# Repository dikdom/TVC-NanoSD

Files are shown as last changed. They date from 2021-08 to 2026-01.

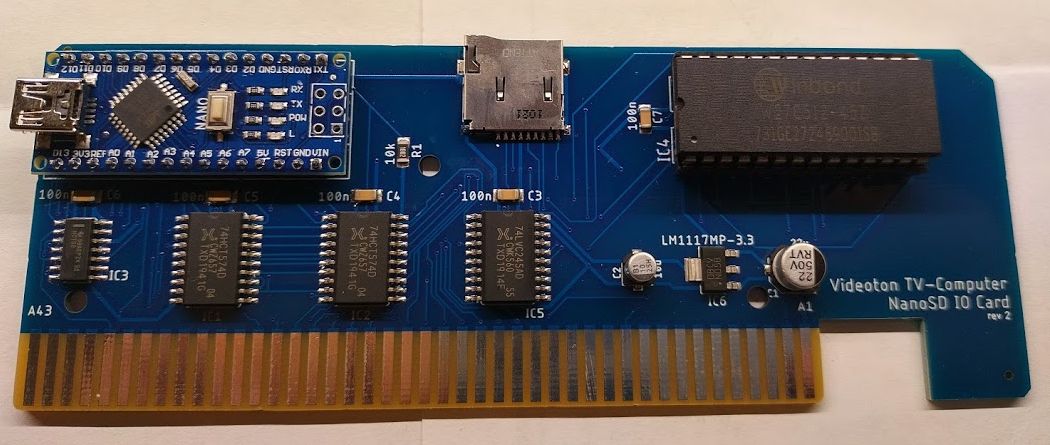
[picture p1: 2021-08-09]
doc/TVC-NanoSD-IO-r2.jpg

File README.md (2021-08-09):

# TVC-NanoSD
A microSD card handler IO card for the Videoton TV Computer.
Egy microSD kártya kezelő IO kártya a Videoton TV Computer számára.

## License
BSD 3-Clause License

## Description
This is a simple and cheap microSD handler card for the Hunarian 8 bit TVC computer. It emulates the cassette interface so it can load
and save .CAS files, it can read and write data files.

## Leírás
Ez egy egyszerű és viszonylag olcsón összerakható microSD kártya kezelő IO modul a magyar 8bites TVC számítógép felső bővítőjébe. A magnó 
interface-t emulálja, így .CAS file-okat olvas és ír (LOAD és SAVE parancs működik) illetve sima adat file-okat is létre lehet hozni vele
az SD kártyán.

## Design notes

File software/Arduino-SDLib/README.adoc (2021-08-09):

:repository-owner: arduino-libraries
:repository-name: SD

= {repository-name} Library for Arduino =





The SD library allows for reading from and writing to SD cards.

For more information about this library please visit us at
http://www.arduino.cc/en/Reference/{repository-name}

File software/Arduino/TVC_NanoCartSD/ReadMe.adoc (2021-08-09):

:Author: sanyi
:Email: {AuthorEmail}
:Date: 19/01/2021
:Revision: version#
:License: Public Domain

= Project: {Project}

Describe your project

== Step 1: Installation
Please describe the steps to install this project.

For example:

1. Open this file
2. Edit as you like
3. Release to the World!

== Step 2: Assemble the circuit

Assemble the circuit following the diagram layout.png attached to the sketch

== Step 3: Load the code

Upload the code contained in this sketch on to your board

=== Folder structure

....
 sketch123                => Arduino sketch folder
  ├── sketch123.ino       => main Arduino file
  ├── schematics.png      => (optional) an image of the required schematics
  ├── layout.png          => (optional) an image of the layout
  └── ReadMe.adoc         => this file
....

=== License
This project is released under a {License} License.

=== Contributing
To contribute to this project please contact sanyi https://id.arduino.cc/sanyi

=== BOM
Add the bill of the materials you need for this project.

|===
| ID | Part name      | Part number | Quantity
| R1 | 10k Resistor   | 1234-abcd   | 10
| L1 | Red LED        | 2345-asdf   | 5
| A1 | Arduino Zero   | ABX00066    | 1
|===

=== Help
This document is written in the _AsciiDoc_ format, a markup language to describe documents.
If you need help you can search the http://www.methods.co.nz/asciidoc[AsciiDoc homepage]
or consult the http://powerman.name/doc/asciidoc[AsciiDoc cheatsheet]

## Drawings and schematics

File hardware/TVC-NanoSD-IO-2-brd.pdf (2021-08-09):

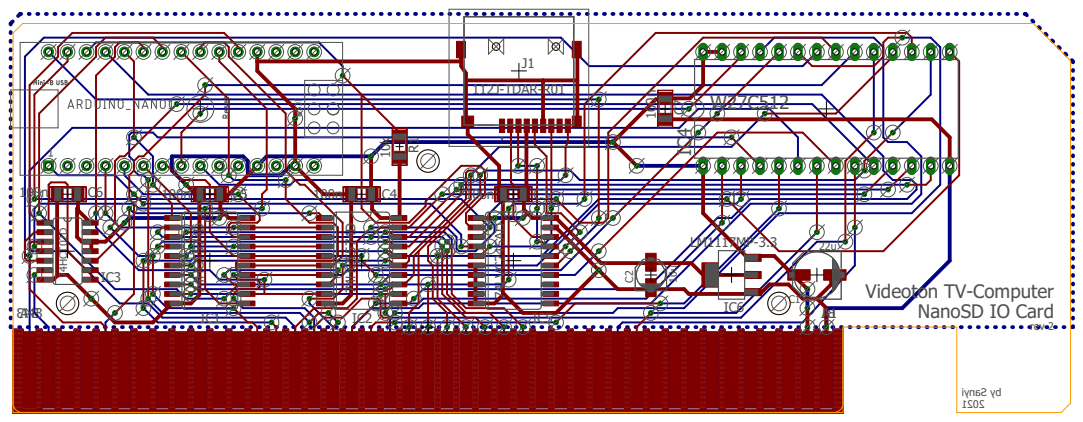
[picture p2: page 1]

i ynaS yb 1202 34B 1B Videoton TV-Computer NanoSD IO Card rev 2 A43 A1 IC1 IC2 IC3 IC4 IC5 C6 C5 C4 C3 J1 R1 IC6 C2 C1 C7 74HCT574D 74HCT574D 74HCT02D W27C512 74LVC245AD 100n 100n 100n 100n 112J-TDAR-R01 10k LM1117MP-3.3 10u 22u 100n

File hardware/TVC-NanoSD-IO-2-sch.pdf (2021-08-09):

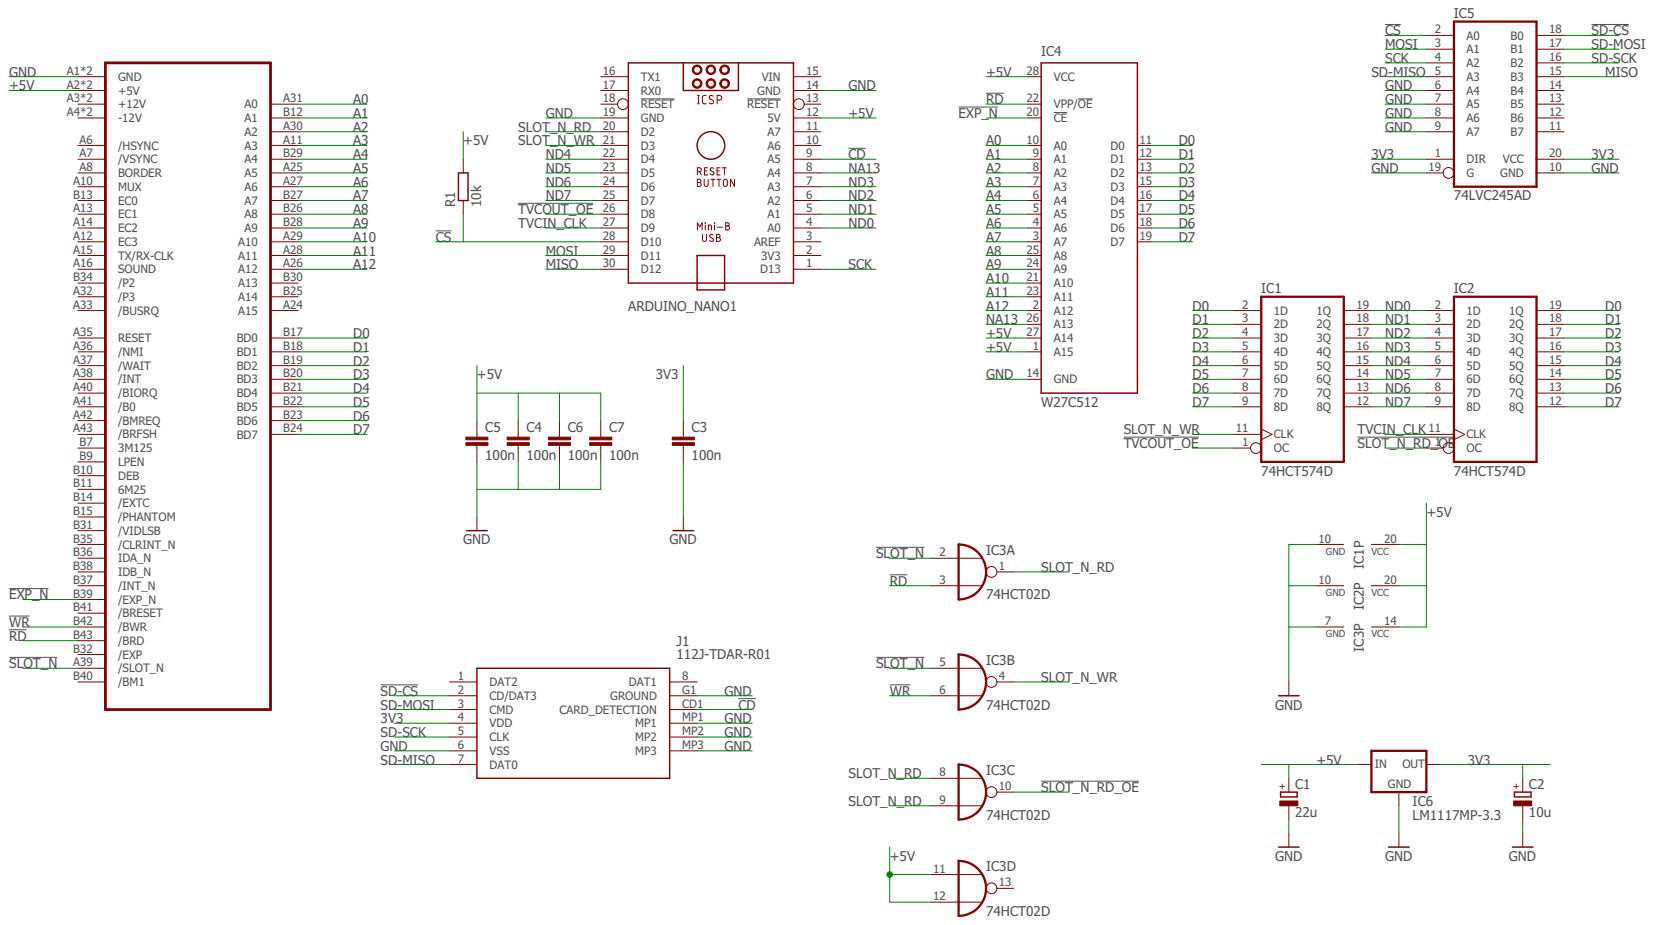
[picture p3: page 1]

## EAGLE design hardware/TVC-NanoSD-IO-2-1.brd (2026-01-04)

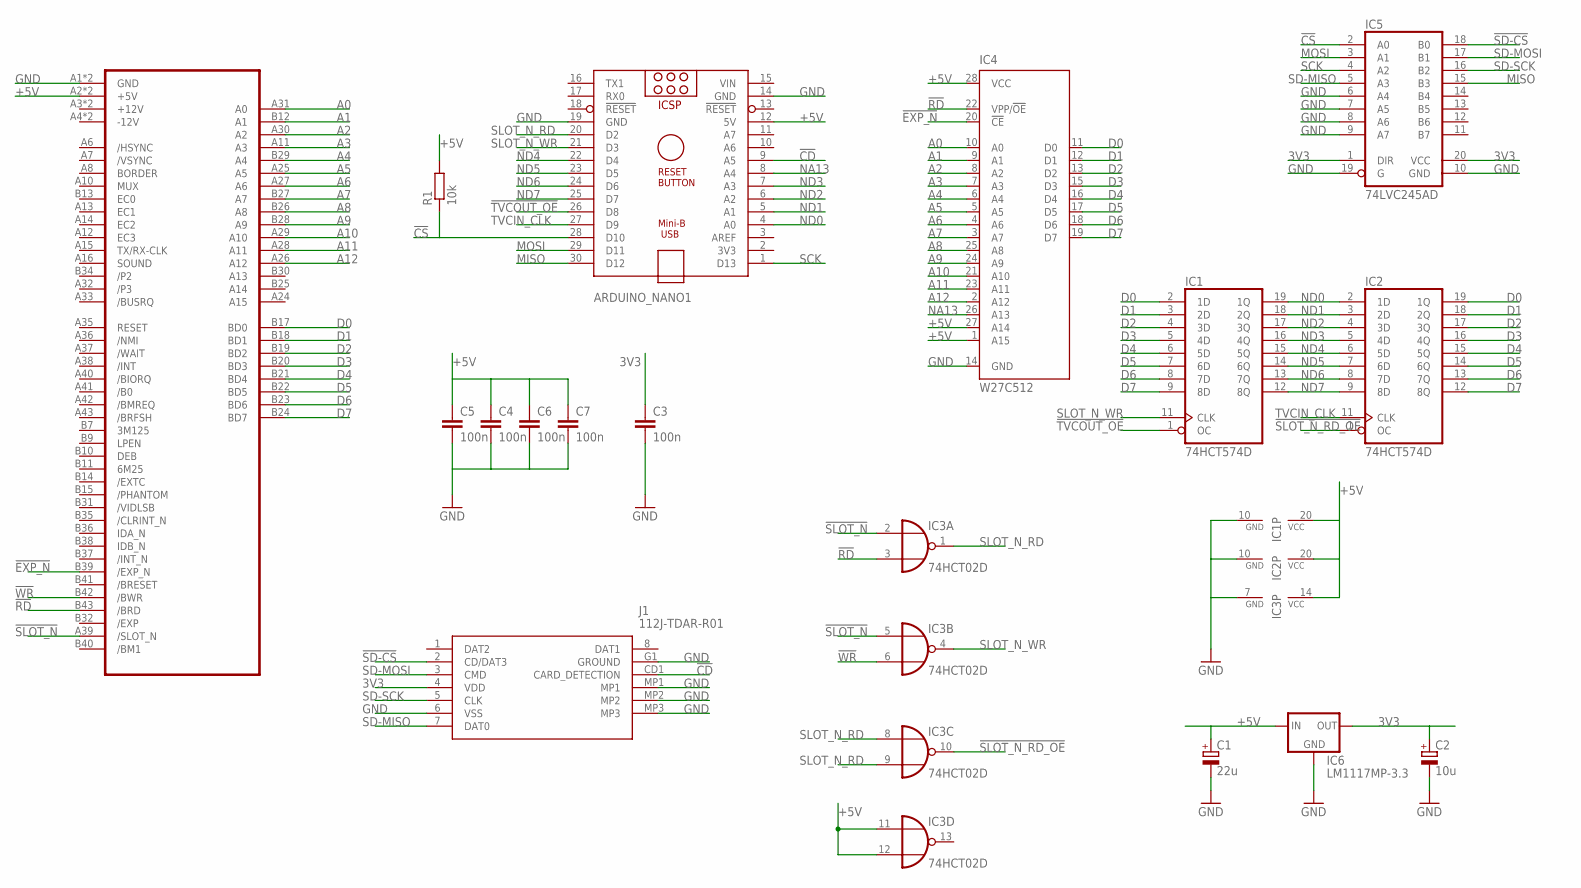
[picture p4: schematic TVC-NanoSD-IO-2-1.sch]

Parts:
ARDUINO_NANO1: ARDUINO_NANO
C1: 22u; PANASONIC_D
C2: 10u; PANASONIC_B
C3, C4, C5, C6, C7: 100n; C1206
CON1: TVC-EXP-HBA-COMMON; TVC-EXP-EDGE
IC1, IC2: 74HCT574D; SO20W
IC3: 74HCT02D; SO14
IC4: W27C512; DIL28-6
IC5: 74LVC245AD; SO20W
IC6: LM1117MP-3.3; SOT223
J1: 112J-TDAR-R01; 112JTDARR01
R1: 10k; R1206

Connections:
3V3: C2.+, C3.1, IC5.1 (DIR), IC5.20 (VCC), IC6.2 (OUT), IC6.4 (OUT), J1.4 (VDD)
!CD: ARDUINO_NANO1.9 (A5), J1.CD1 (CARD_DETECTION)
!CS: ARDUINO_NANO1.28 (D10), IC5.2 (A0), R1.1
!EXP_N: CON1.B39 (/EXP_N), IC4.20 (!CE)
!RD: CON1.B43 (/BRD), IC3.3 (I1), IC4.22 (VPP/!OE)
!SD-CS: IC5.18 (B0), J1.2 (CD/DAT3)
!SLOT_N: CON1.A39 (/SLOT_N), IC3.2 (I0), IC3.5 (I0)
!SLOT_N_RD_OE: IC2.1 (OC), IC3.10 (O)
!TVCOUT_OE: ARDUINO_NANO1.26 (D8), IC1.1 (OC)
!WR: CON1.B42 (/BWR), IC3.6 (I1)
+5V: ARDUINO_NANO1.12 (5V), C1.+, C4.1, C5.1, C6.1, C7.1, CON1.A2 (+5V), CON1.B2 (+5V), IC1.20 (VCC), IC2.20 (VCC), IC3.11 (I0), IC3.12 (I1), IC3.14 (VCC), IC4.1 (A15), IC4.27 (A14), IC4.28 (VCC), IC6.3 (IN), R1.2
A0: CON1.A31 (A0), IC4.10 (A0)
A1: CON1.B12 (A1), IC4.9 (A1)
A2: CON1.A30 (A2), IC4.8 (A2)
A3: CON1.A11 (A3), IC4.7 (A3)
A4: CON1.B29 (A4), IC4.6 (A4)
A5: CON1.A25 (A5), IC4.5 (A5)
A6: CON1.A27 (A6), IC4.4 (A6)
A7: CON1.B27 (A7), IC4.3 (A7)
A8: CON1.B26 (A8), IC4.25 (A8)
A9: CON1.B28 (A9), IC4.24 (A9)
A10: CON1.A29 (A10), IC4.21 (A10)
A11: CON1.A28 (A11), IC4.23 (A11)
A12: CON1.A26 (A12), IC4.2 (A12)
D0: CON1.B17 (BD0), IC1.2 (1D), IC2.19 (1Q), IC4.11 (D0)
D1: CON1.B18 (BD1), IC1.3 (2D), IC2.18 (2Q), IC4.12 (D1)
D2: CON1.B19 (BD2), IC1.4 (3D), IC2.17 (3Q), IC4.13 (D2)
D3: CON1.B20 (BD3), IC1.5 (4D), IC2.16 (4Q), IC4.15 (D3)
D4: CON1.B21 (BD4), IC1.6 (5D), IC2.15 (5Q), IC4.16 (D4)
D5: CON1.B22 (BD5), IC1.7 (6D), IC2.14 (6Q), IC4.17 (D5)
D6: CON1.B23 (BD6), IC1.8 (7D), IC2.13 (7Q), IC4.18 (D6)
D7: CON1.B24 (BD7), IC1.9 (8D), IC2.12 (8Q), IC4.19 (D7)
GND: ARDUINO_NANO1.14 (GND), ARDUINO_NANO1.19 (GND), C1.-, C2.-, C3.2, C4.2, C5.2, C6.2, C7.2, CON1.A1 (GND), CON1.B1 (GND), IC1.10 (GND), IC2.10 (GND), IC3.7 (GND), IC4.14 (GND), IC5.6 (A4), IC5.7 (A5), IC5.8 (A6), IC5.9 (A7), IC5.10 (GND), IC5.19 (G), IC6.1 (GND), J1.6 (VSS), J1.G1 (GROUND), J1.MP1, J1.MP2, J1.MP3
MISO: ARDUINO_NANO1.30 (D12), IC5.15 (B3)
MOSI: ARDUINO_NANO1.29 (D11), IC5.3 (A1)
NA13: ARDUINO_NANO1.8 (A4), IC4.26 (A13)
ND0: ARDUINO_NANO1.4 (A0), IC1.19 (1Q), IC2.2 (1D)
ND1: ARDUINO_NANO1.5 (A1), IC1.18 (2Q), IC2.3 (2D)
ND2: ARDUINO_NANO1.6 (A2), IC1.17 (3Q), IC2.4 (3D)
ND3: ARDUINO_NANO1.7 (A3), IC1.16 (4Q), IC2.5 (4D)
ND4: ARDUINO_NANO1.22 (D4), IC1.15 (5Q), IC2.6 (5D)
ND5: ARDUINO_NANO1.23 (D5), IC1.14 (6Q), IC2.7 (6D)
ND6: ARDUINO_NANO1.24 (D6), IC1.13 (7Q), IC2.8 (7D)
ND7: ARDUINO_NANO1.25 (D7), IC1.12 (8Q), IC2.9 (8D)
SCK: ARDUINO_NANO1.1 (D13), IC5.4 (A2)
SD-MISO: IC5.5 (A3), J1.7 (DAT0)
SD-MOSI: IC5.17 (B1), J1.3 (CMD)
SD-SCK: IC5.16 (B2), J1.5 (CLK)
SLOT_N_RD: ARDUINO_NANO1.20 (D2), IC3.1 (O), IC3.8 (I0), IC3.9 (I1)
SLOT_N_WR: ARDUINO_NANO1.21 (D3), IC1.11 (CLK), IC3.4 (O)
TVCIN_CLK: ARDUINO_NANO1.27 (D9), IC2.11 (CLK)
VIN: ARDUINO_NANO1.15 (VIN)

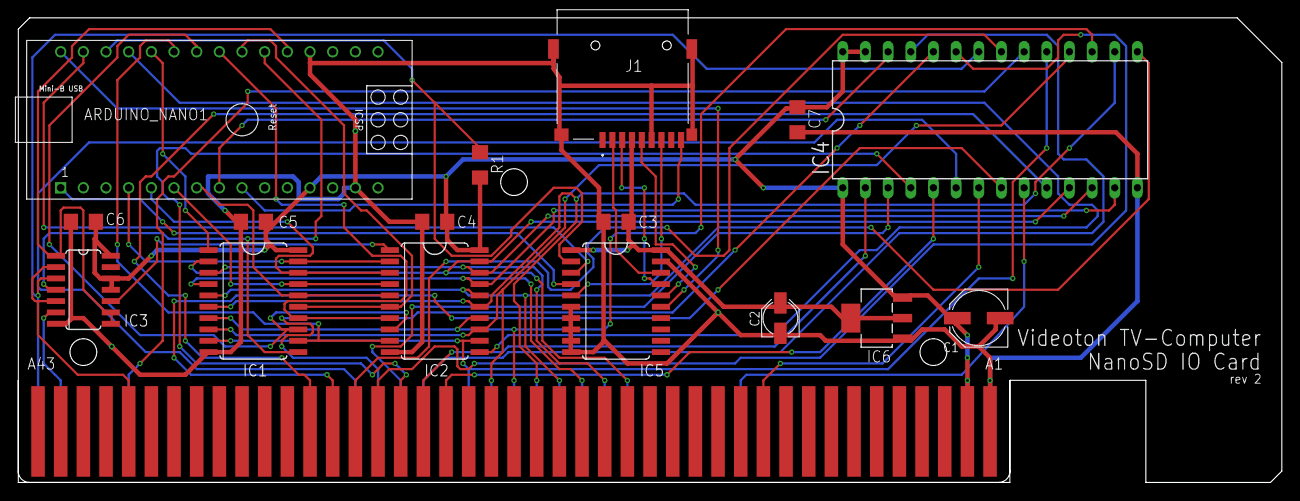
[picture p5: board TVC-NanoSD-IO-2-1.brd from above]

Board: 2 copper layers, 141.6 x 52.1 mm, 17 parts (0 on the bottom side), 51 nets.

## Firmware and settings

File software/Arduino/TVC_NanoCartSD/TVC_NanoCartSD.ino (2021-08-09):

/*
  This is the NanoSD IO Card's Arduino Nano firmware code. This is the code that communicates with TVC
  and reads/writes the SD card.

  Pins to avoid: D0, D1 (RX/TX)
  The Nano board has to have
  - 8 lines to the data bus of TVC -  PORTC0-3: BD0-BD3 (A0-A3)
                                      PORTD4-7: BD4-BD7 (pin 4-pin 7)
  - 6 lines to the control
    - /SLOTn + /RD PD2 (pin 2)  Always IN, INT0, TVC port in
    - /SLOTn + /WR PD3 (pin 3)  Always IN, INT1, TVC port out
    - /LE on TVC-IN register  PB0 (pin 8)    Always OUT
    - /OE on TVC-OUT register PB1 (pin 9)    Always OUT
    - BANK-Sel (pin A4)   Always OUT   - as of now, NanoSD EEPROM code fits in one bank, this feature is not in use
    - Card Detect PC5 (pin A5) Always IN, shall be pulled UP internally
  - 4 lines to SD card (SPI):
    - PB3, PB4, PB5 (MOSI, MISO, CLK; pin 11, 12, 13)
    - PB2 (CS; pin 10)                - Always OUTPUT

  Always TVC initiates a command
  OPEN: opens a file for reading
    TVC OUTs to address 00 an OPEN command
    then OUTs a fileName with 0 delimiter. The fileName is max 64 chars long
    TVC INs and waits for OPEN_OK or FILE_NOT_FOUND.
    WAITING_FOR_INPUT (string was not terminated properly) and DATA_NOT_READY_YET are normal, intermediate responses.
    In case of FILE_NOT_FOUND the file cannot be opened. In case of OPEN_OK then the file size can be read from stream
    (low/high byte)
  CLOSE: close a previously opened file
    TVC OUTs to address 00 a CLOSE command
    TVC INs and waits for CLOSE_OK or CLOSE_FAILED.
  GETDATA: get data content from an open file
    TVC OUTs to 00 a GETDATA command
    -- repeat from here
    TVC INs until OK, END_OF_FILE or FILE_NOT_OPEN. DATA_NOT_READY_YET is normal, intermediate response.
    END_OF_FILE means TVC read all the bytes, operation shall finish here.
    After OK, TVC continues reading and the card returns a number, how many bytes (n) are available in its
    buffer, then the data. After that TVC reads (IN from address 00) n bytes.
    After n bytes read TVC must ack the read by OUTing ACK_GETDATA and repeat the read procedure. Anything else
    than ACK_GETDATA will cancel the getData stream, empties the buffer of the card.
  LIST: list the directory of the current dir
    TVC OUTs to 00 a LIST command
    -- repeat from here
    TVC INs until OK, END_OF_LIST, CARD_NOT_READY, DATA_NOT_READY_YET. DATA_NOT_READY_YET is a normal, intermediate response.
    END_OF_LIST means there is no more files in the list and the operation shall finish here.
    After OK, the card returns null terminated string, then a type, then a size (0 in case of directory).
    After all bytes received, TVC must ACK_LIST file record and repeat the procedure.
  CHDIR: changes directory
    TVC OUTs to 00 a CHDIR command
    TVC OUTs a path as a null terminated string. Max length is 64 chars. Can be absolute or relative path. Nano code stores the working path
    as the SD library doesn't support that.
    "/" is the root directory.
    If a path starts with "/" it is handled as absolute path and that will be working directory (if it exists).
    Otherwise it is added to the stored working directory and that will be used for the subsequent CHDIR, LIST and OPEN commands
    The path may or may not ends with "/"
    TVC can receive CHDIR_OK or CHDIR_FAILED and and intermediate DATA_NOT_READY_YET or WAITING_FOR_INPUT (if path is not terminated yet).
*/

#include <SPI.h>
#include <SD.h>
#include <wiring_private.h>
#include "CircularQueue.h"
#include "PathStack.h"
#include <string.h>
#include <EEPROM.h>

#define INPUTDATABUFFER_SIZE 64+16
#define OUTPUTDATABUFFER_SIZE 64+16
#define GETDATA_SIZE 64

#define LINE_TVCOUT_OE  PB0
#define LINE_TVCIN_CLK  PB1
#define LINE_SLOTN_RD   PD2
#define LINE_SLOTN_WR   PD3
#define LINE_BANK       PC4
#define LINE_CD         PC5

#define LINE_DATA0      PC0
#define LINE_DATA1      PC1
#define LINE_DATA2      PC2
#define LINE_DATA3      PC3
#define LINE_DATA4      PD4
#define LINE_DATA5      PD5
#define LINE_DATA6      PD6
#define LINE_DATA7      PD7

#define LINE_SS         PB2
#define LINE_MISO       PB3
#define LINE_MOSI       PB4
#define LINE_CLK        PB5
#define LINE_CS         PB2  // SS is not used in Master SPI mode

#define DEBUG

enum COMMANDS { OPEN = 0, // Open a file. Parameter is a null terminated string. Returns 0: ok
                CLOSE,   // Closes the lastopen file. Returns OK
                CHDIR,   // Change dir. Parameter is a null terminated string. Returns 0:ok, 1:FILE_NOT_FOUND
                LIST,    // Gets the list of files in the current directory (fName, type, size)
                ACK_LIST, //
                GETDATA,   // Returns OK, then [num of bytes to return (GETDATA_SIZE)]. After num of bytes read TVC must send ACK_GETDATA;
                FINFO,   // Returns the file info. Param: null terminated file name.
                GETCDIR,  // Returns the current path: length of string + string
                BANKTO0,  // NOTIMPLEMENTED YET!
                BANKTO1,
                CREATE, // 0x0a gets a fileName (length + chars), fileType (0x01 or 0x11), return CREATE_OK of CREATE_FAILED
                PUTDATA,
                CLOSEWRITE,
                GETPARAMETER, // 0x0D gets a parameter from Nano
                SETPARAMETER, // 0x0E sets a parameter to Nano
                MKDIR,
                RMDIR,  // 0x10 - removes an empty directory from SDs
                DELETE,
                CDPINCHANGE_DETECTED,
                NONE = 255
              };
enum STATUS  {OK = 0,
              OPEN_OK,
              DATA_NOT_READY_YET = 0x80,  // not sent from outputQueue
              WAITING_FOR_INPUT,
              FILE_NOT_FOUND,
              END_OF_FILE,
              END_OF_LIST,
              FILE_NOT_OPEN,              // 0x85
              CARD_NOT_READY,
              READ_OUT_OF_SYNC,
              BUFFER_OVERRUN,
              BUFFER_UNDERRUN,
              CLOSE_OK,                     // 0x8a
              CLOSE_FAILED,
              CHDIR_OK,
              CHDIR_FAILED,                 // 0x8d
              BANK_SELECT_DONE,
              CREATE_OK,
              CREATE_FAILED,                // 0x90
              DATA_RECEIVED,
              DATA_FAILED_TO_RECEIVE,
              MKDIR_OK,                     // 0x93
              MKDIR_FAILED,
              RMDIR_OK,                     // 0x95
              RMDIR_FAILED,
              DELETE_OK,
              DELETE_FAILED,                // 0x98
              INVALID_PARAMETER_ID,
              PARAMETER_SET,                 // 0x9
              STATUS_NO_SD  = 0xFF
             };

enum FILETYPE { DIRECTORY = 0,
                PLAINFILE
              };

enum PARAMETERS {
                PARAM_MENU_STATUS = 0,
                PARAM_DEFAULT_SORT,
                PARAM_SD_STATE,
                PARAM_NANO_VERSION
                };

enum MENUSTATUS {MENUSTATUS_OFF = 0,
                 MENUSTATUS_ON
                };

const int chipSelect = 10; // LINE_CS!!
const char NANOSD_ID[] PROGMEM = "NanoSD Arduino fw v0.32";

Sd2Card card;
SdVolume volume;
SdFile root;

CircularQueue inputQueue = new CircularQueue(INPUTDATABUFFER_SIZE);
CircularQueue outputQueue = new CircularQueue(OUTPUTDATABUFFER_SIZE);
enum COMMANDS currentCommand = NONE;
volatile enum STATUS status = WAITING_FOR_INPUT;
File openFile;
File currentDirFile;
union {
  long remainingBytes;
  long bytesWritten;
} fileSizeCounter;
byte savingFileType;
//long remainingBytes = 0;
bool fileIsOpen = false;
String currentDir = "/";
volatile bool sdInitialized = false;
byte memoryBankMapStore = 0;

void setup() {

  DDRD =  DDRD & 0x03;    // Leave RX and TX as they are, the rest is set to input (d4-d7, SLOTn, d3?)
  DDRC =  (1 << LINE_BANK); // Setting data lines and card detect to input and BANK line (PC4) to output
  PORTC = (1 << LINE_CD); // BANK to low, enable pullup on LINE_CD
  DDRB = (1 << LINE_TVCIN_CLK) | (1 << LINE_TVCOUT_OE) | (1 << LINE_SS) | (1 << LINE_MOSI) | (1 << LINE_CLK); // Clock, Output enable to output
  PORTB = (1 << LINE_TVCIN_CLK) | (1 << LINE_TVCOUT_OE); // set clock and output enable set to high

#ifdef DEBUG
  Serial.begin(9600);
  while (!Serial) {}
  Serial.print(F("PINC: ")); Serial.println(PINC, BIN);
#endif

  if (sdInitialized = SD.begin(chipSelect)) { // SD.begin must be called when timer0 overflow INT is enabled.
    status = DATA_NOT_READY_YET;
    currentDirFile = SD.open("/");
  }
  if ((!sdInitialized) || (!currentDirFile)) {
    status = CARD_NOT_READY;
  }

#ifndef DEBUG
  TIMSK0 &= ~_BV(TOIE0); // disable timer0 overflow interrupt, Serial uses it
#endif

  initTVC_IN_register();

  noInterrupts();
  EICRA = _BV(ISC00) | _BV(ISC01) | _BV(ISC10) | _BV(ISC11) ; // Falling edge on on INT0/1 generates an interrupt request.
  EIMSK |= (1 << INT0) | (1 << INT1);

  PCICR = _BV(PCIE1);   // enable port change int on PC5(PCI13)
  PCIFR = _BV(PCIF1);            // clear earlier interrupts on PCI - if any..
  PCMSK1 = _BV(PCINT13); // enable PCI on pin PCI13 which is PORTC5
  interrupts();
#ifdef DEBUG
  Serial.println(F("NanoSD setup() executed!"));
  Serial.print(F("SD initialized: ")); Serial.println(sdInitialized ? F("true") : F("false"));
  Serial.print(F("root dir: ")); Serial.println(currentDirFile ? F("valid") : F("invalid"));
  Serial.print(F("PINC: ")); Serial.println(PINC, BIN);
#endif
}

void initTVC_IN_register() {
  cbi(PORTB, LINE_TVCIN_CLK);  // CLOCK into register

  DDRD = B11110000;
  DDRC = B00001111 | _BV(LINE_BANK);

  PORTD = status & 0xf0;
  PORTC = (status & 0x0f) | _BV(LINE_CD);

  asm("NOP");
  asm("NOP");
  PORTB |= _BV(LINE_TVCIN_CLK);
  asm("NOP");
  PORTB &= ~_BV(LINE_TVCIN_CLK);
  asm("NOP");

  DDRD = B00000000;
  DDRC = _BV(LINE_BANK);
}

// IO access
ISR(INT0_vect) { // pin 2 (PD2) fell - RD from register happened - several cycles ago
    #ifdef DEBUG
      Serial.println(F("Z80 IN execution..."));
    #endif


  DDRD = B11110000;
  DDRC = B00001111 | _BV(LINE_BANK);

  byte localStatus = status;

  if ((localStatus & 0x80) != 0) {
    PORTD = localStatus & 0xf0;
    PORTC = (localStatus & 0x0f) | memoryBankMapStore | (1 << LINE_CD);
  } else if (!outputQueue.isEmpty()) {
    byte data = outputQueue.pop();
    PORTD = data & 0xf0;
    PORTC = (data & 0x0f) | memoryBankMapStore | (1 << LINE_CD);
    #ifdef DEBUG
      Serial.print(F("Data on PORTC and PORTD: "));Serial.println(data);
    #endif
  } else {
    PORTD = BUFFER_UNDERRUN & 0xf0;
    PORTC = (BUFFER_UNDERRUN & 0x0f) | memoryBankMapStore | (1 << LINE_CD);
  }
  // the data is set on data bus

  asm("NOP");   // let's leave some time to stabilize the data lines
  asm("NOP");

  cbi(PORTB, LINE_TVCIN_CLK);  // CLOCK into register t
  asm("NOP");
  sbi(PORTB, LINE_TVCIN_CLK);  // CLOCK into register done. TVC will read it next time
  asm("NOP");   // let's leave some time to keep the data lines (5-10 ns required)

  DDRD = B00000000;
  DDRC = _BV(LINE_BANK);
}

ISR(INT1_vect) { // pin 3 (PD3) change - WR to register happened
  // TVC wrote into register, let's read it and pass for processing
  cbi(PORTB, LINE_TVCOUT_OE);
  asm("NOP");
  asm("NOP");
  asm("NOP");
  byte datal = PINC;
  byte datah = PIND;
  sbi(PORTB, LINE_TVCOUT_OE);

  if (!inputQueue.isFull()) {
    datal = (datal & 0x0f) | (datah & 0xf0);
    inputQueue.push(datal);
  } else {
    status = BUFFER_OVERRUN;
    // TODO handle buffer is full!
  }
}

ISR (PCINT1_vect) {
  inputQueue.push(CDPINCHANGE_DETECTED);
  PCICR = 0x00; // let's not disturb the main loop for a while...
}

void handleOpen() {
  String fileName = "";
  byte c;
  status = WAITING_FOR_INPUT;
  if (fileIsOpen) {
    openFile.close();
  }
  while ((c = inputQueue.pop()) != 0) {
    fileName += (char)c;
  }

#ifdef DEBUG
  Serial.print(F("Received fileName: '")); Serial.print(fileName); Serial.println('\'');
#endif

  status = DATA_NOT_READY_YET;

  if (fileName.equals("")) {
    // no filename given, return the first/next file in the directory
    while (openFile = currentDirFile.openNextFile()) {
      if (openFile.isDirectory()) {
        continue;
      } else {
        fileName = openFile.name();
        if (fileName.endsWith(F(".CAS"))) {
#ifdef DEBUG
          Serial.print(F("File found: ")); Serial.println(fileName);
#endif
          break;
        }
      }
    }
  } else {
    if (!fileName.startsWith("/")) {
      fileName = currentDir + fileName;
    }
    fileName.toUpperCase();
    if (!SD.exists(fileName) && !fileName.endsWith(F(".CAS"))) {
      fileName += F(".CAS");
    }
#ifdef DEBUG
    Serial.print(F("File to open: ")); Serial.println(fileName);
#endif
    openFile = SD.open(fileName);
  }

  if (openFile) {
    fileName = openFile.name();
    fileName.toUpperCase();
#ifdef DEBUG
    Serial.print(F("fileName: ")); Serial.println(fileName);
#endif
    byte fileType = openFile.read();
    boolean casFile = fileName.endsWith(F(".CAS")) &&
                      ((fileType == 0x01) || (fileType == 0x11));
    fileName = fileName.substring(0, fileName.length() - 4);
#ifdef DEBUG
    Serial.print(F("File found, sending back the fileName: "));
    Serial.print(fileName); Serial.print(F(" (length: ")); Serial.print(fileName.length()); Serial.println(')');
#endif
    outputQueue.push((byte)fileName.length());
    for (int i = 0; i < fileName.length(); i++) {
      outputQueue.push(fileName.charAt(i));
    }
    fileSizeCounter.remainingBytes = openFile.size();
    if (casFile) {
      fileSizeCounter.remainingBytes -= 0x80;
      openFile.seek(0x80);
    } else {
#ifdef DEBUG
      Serial.println(F("Not a CAS file."));
#endif
      // in case of non-cas file, the full file is available
      openFile.seek(0);
    }
#ifdef DEBUG
    Serial.print(F("File size to TVC is: ")); Serial.println(fileSizeCounter.remainingBytes);
#endif
    outputQueue.push((byte)(fileSizeCounter.remainingBytes &  0x000000ff));
    outputQueue.push((byte)((fileSizeCounter.remainingBytes & 0x0000ff00) >> 8));
    outputQueue.push((byte)((fileSizeCounter.remainingBytes & 0x00ff0000) >> 16));
    outputQueue.push((byte)((fileSizeCounter.remainingBytes & 0xff000000) >> 24));

    status = OPEN_OK;
    fileIsOpen = true;
  } else {
    status = FILE_NOT_FOUND;
    fileIsOpen = false;
#ifdef DEBUG
    Serial.println(F("not found"));
#endif
  }
}

void handleClose() {
  if (fileIsOpen) {
    openFile.close();
    fileIsOpen = false;
#ifdef DEBUG
    Serial.println(F("File closed!"));
  } else {
    Serial.println(F("No file to close.."));
#endif
  }
  fileSizeCounter.remainingBytes = 0;
  outputQueue.clear();
  status = CLOSE_OK;
}

void handleGetData() {
  byte readBuffer[GETDATA_SIZE + 1];
  int len = 0;
  byte toRead = min(fileSizeCounter.remainingBytes, GETDATA_SIZE);
  if(toRead>0) {
    do {
      len = openFile.read(&readBuffer[1], toRead);
    } while (len==0 && openFile.available()>0);
  } else {
    len = 0;
  }
#ifdef DEBUG
  Serial.print(F("To Read: "));Serial.print(toRead);Serial.print(F(", read len: "));Serial.print(len);Serial.print(F(", available: "));Serial.println(openFile.available());
  Serial.print(F("File buffer read, len: "));Serial.println(len);
#endif
  if (len > 0) {
    readBuffer[0] = len;
    outputQueue.pushBlock(len + 1, readBuffer);
    fileSizeCounter.remainingBytes -= len;
#ifdef DEBUG
    Serial.print(F("Content added to outputQueue: "));Serial.print(len);
    Serial.print(F(" Queue size(): "));Serial.print(outputQueue.getSize());
    Serial.print(F(" Remaining size:"));Serial.println(fileSizeCounter.remainingBytes);
#endif
    status = OK;
  } else {
    // EOF
    status = END_OF_FILE;
#ifdef DEBUG
    Serial.println(F("EOF reached!"));
#endif
  }
}

byte fillFileInfoBuffer(File f, byte* data) {
  char *name = f.name();
  int pos = strlen(name);
  int len = pos;
  for (int i = 0; i < 12; i++) {
    if (i < pos) {
      data[i] = name[i];
    } else {
      data[i] = 0x20;
    }
  }
  pos = 12;
  data[pos++] = f.isDirectory() ? DIRECTORY : PLAINFILE;
  unsigned long fSize = f.size();
  if (f.isDirectory()) {
    data[pos++] = 0;
    data[pos++] = 0;
    data[pos++] = 0;
    data[pos++] = 0;
  } else {
    if((len > 3) && !strcmp(f.name()+len-4, ".CAS")) {
      fSize -= 128;  // Cheat here, let's not check the first byte..
    }
    data[pos++] = (byte)(fSize & 0xff);
    data[pos++] = (byte)((fSize & 0xff00) >> 8);
    data[pos++] = (byte)((fSize & 0xff0000) >> 16);
    data[pos++] = (byte)((fSize & 0xff000000) >> 24);
  }
  return pos;
}

bool endsWith(char *str, char *post) {
  int lenStr = strlen(str);
  int lenPst = strlen(post);
  int pos = lenStr - lenPst;
  int idx = 0;
  while (pos + idx < lenStr && str[pos + idx] == post[idx]) {
    idx++;
  }
  return pos + idx == lenStr;
}

void handleList() {
  byte data[18];  // OK(1) filename8.3(8+1+3 = 12) type(1) filesize(4)
  data[0] = OK;
  File cDir = SD.open(currentDir);
  File entry;
#ifdef DEBUG
  int c = 0;
  long delayFirst = 0;
  long delayLast = 0;
  long timeStamp = millis();
#endif
  while (entry = cDir.openNextFile()) {
#ifdef DEBUG
    if(c==0) {
      delayFirst = millis() - timeStamp;
    }else {
      delayLast = millis() - timeStamp;
    }
    c++;
#endif
    fillFileInfoBuffer(entry, &data[1]);
    entry.close();
// #ifdef DEBUG
//     for (int i = 0; i < 18; i++) {
//       Serial.print(data[i], HEX); Serial.print(' ');
//     }
//     Serial.println();
// #endif
    outputQueue.pushBlock(18, data);
    status = OK;
// #ifdef DEBUG
//     Serial.println(F("Data sent"));
// #endif
    byte ack = inputQueue.pop();
    status = DATA_NOT_READY_YET;
// #ifdef DEBUG
//     Serial.print(F("Answer: ")); Serial.println(ack);
// #endif

    if (ack != ACK_LIST) {
      status = READ_OUT_OF_SYNC;
      outputQueue.clear();
#ifdef DEBUG
  Serial.print(F("No ACK_LIST arrived, instead: "));Serial.println(ack);
#endif
      break;
    }
#ifdef DEBUG
    timeStamp = millis();
#endif
  }

  status = END_OF_LIST;
#ifdef DEBUG
  Serial.println(F("List done"));
  Serial.print(F("First delay: ")); Serial.print(delayFirst); Serial.print(F("ms, Last delay: ")); Serial.print(delayLast);
  Serial.print(F("ms, count: "));Serial.println(c);
#endif

  cDir.close();
}

String getFilePath() {
  PathStack ps;
  byte c;
  String fileName = "";
  while ((c = inputQueue.pop()) != 0) {
    fileName += (char)c;
  }
  status = DATA_NOT_READY_YET;
#ifdef DEBUG
  Serial.print(F("CD path arrived: ")); Serial.println(fileName);
#endif
  if (fileName.startsWith("./")) {
    fileName = fileName.substring(2);
  }
  if (!fileName.startsWith("/")) {
    fileName = currentDir + fileName;
  }
  if (!fileName.endsWith("/")) {
    fileName += "/";
  }
#ifdef DEBUG
  Serial.print(F("Preconverted name: ")); Serial.println(fileName);
#endif

  byte pos = 0;
  byte startPos = 0;
  byte len = fileName.length();
  while ((startPos < len) && (pos = fileName.indexOf("/", startPos)) != -1) {
#ifdef DEBUG
    Serial.print(F("startPos: ")); Serial.print(startPos);
    Serial.print(F(", pos: ")); Serial.println(pos);
#endif

    String p = fileName.substring(startPos, pos + 1);
#ifdef DEBUG
    Serial.print(F("after substring: '")); Serial.println(fileName);
#endif

    if (p != "../") {
      ps.push(startPos, pos + 1);
    } else {
      ps.dropTop();
    }
    startPos = pos + 1;
  }
  fileName = ps.getAbsolutePath(fileName);
#ifdef DEBUG
  Serial.print(F("Converted path: '")); Serial.print(fileName); Serial.println('\'');
#endif
  return fileName;
}
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
void loop() {
  currentCommand = inputQueue.pop(); // blocks until a command is pushed
  status = DATA_NOT_READY_YET;
  //  Commands only with SD card present
  if (sdInitialized) {
#ifdef DEBUG
    Serial.print(F("New command: "));
    Serial.println(currentCommand);
#endif
    switch (currentCommand) {
      case OPEN:
        handleOpen();
        break;
      case CLOSE:
        handleClose();
        break;
      case GETDATA:
        handleGetData();
        break;
      case LIST:
        handleList();
        break;
      case CHDIR:
        handleChDir();
        break;
      case FINFO:
        handleFileInfo();
        break;
      case GETCDIR:
        handleGetCDir();
        break;
      case BANKTO0:
        handleBank(0);
        break;
      case BANKTO1:
        handleBank(1);
        break;
      case CREATE:
        handleCreate();
        break;
      case PUTDATA:
        handlePutData();
        break;
      case CLOSEWRITE:
        handleCloseForWrite();
        break;
      case GETPARAMETER:
        handleGetParameter();
        break;
      case SETPARAMETER:
        handleSetParameter();
        break;
      case MKDIR:
        handleMkDir();
        break;
      case RMDIR:
        handleRmDir();
        break;
      case DELETE:
        handleDelete();
        break;
     case CDPINCHANGE_DETECTED:
        handleCDPinChangeDetected();
        break;
     default:
#ifdef DEBUG
        Serial.print(F("unknown command: ")); Serial.println(currentCommand);
#endif
        break;
    }
  } else {
#ifdef DEBUG
  Serial.print(F("No SD card inserted, cmd: "));Serial.println(currentCommand);
#endif
    switch (currentCommand) {
      case GETPARAMETER:
        handleGetParameter();
        break;
      case CDPINCHANGE_DETECTED:
        handleCDPinChangeDetected();
        break;
      case 254:
        outputQueue.push(75);
        status=OK;
#ifdef DEBUG
  Serial.print(F("Sent 75!"));
#endif
        break;
      default:
        status = STATUS_NO_SD;
        noInterrupts();
        inputQueue.clear();
        interrupts();
    }
  }
}

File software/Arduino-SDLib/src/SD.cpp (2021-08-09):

/*

  SD - a slightly more friendly wrapper for sdfatlib

  This library aims to expose a subset of SD card functionality
  in the form of a higher level "wrapper" object.

  License: GNU General Public License V3
          (Because sdfatlib is licensed with this.)

  (C) Copyright 2010 SparkFun Electronics


  This library provides four key benefits:

     Including `SD.h` automatically creates a global
     `SD` object which can be interacted with in a similar
     manner to other standard global objects like `Serial` and `Ethernet`.

     Boilerplate initialisation code is contained in one method named
     `begin` and no further objects need to be created in order to access
     the SD card.

     Calls to `open` can supply a full path name including parent
     directories which simplifies interacting with files in subdirectories.

     Utility methods are provided to determine whether a file exists
     and to create a directory hierarchy.


  Note however that not all functionality provided by the underlying
  sdfatlib library is exposed.

*/

/*

  Implementation Notes

  In order to handle multi-directory path traversal, functionality that
  requires this ability is implemented as callback functions.

  Individual methods call the `walkPath` function which performs the actual
  directory traversal (swapping between two different directory/file handles
  along the way) and at each level calls the supplied callback function.

  Some types of functionality will take an action at each level (e.g. exists
  or make directory) which others will only take an action at the bottom
  level (e.g. open).

*/

#include "SD.h"

namespace SDLib {

  // Used by `getNextPathComponent`
#define MAX_COMPONENT_LEN 12 // What is max length?
#define PATH_COMPONENT_BUFFER_LEN MAX_COMPONENT_LEN+1

  bool getNextPathComponent(const char *path, unsigned int *p_offset,
                            char *buffer) {
    /*

      Parse individual path components from a path.

        e.g. after repeated calls '/foo/bar/baz' will be split
             into 'foo', 'bar', 'baz'.

      This is similar to `strtok()` but copies the component into the
      supplied buffer rather than modifying the original string.


      `buffer` needs to be PATH_COMPONENT_BUFFER_LEN in size.

      `p_offset` needs to point to an integer of the offset at
      which the previous path component finished.

      Returns `true` if more components remain.

      Returns `false` if this is the last component.
        (This means path ended with 'foo' or 'foo/'.)

    */

    // TODO: Have buffer local to this function, so we know it's the
    //       correct length?

    int bufferOffset = 0;

    int offset = *p_offset;

    // Skip root or other separator
    if (path[offset] == '/') {
      offset++;
    }

    // Copy the next next path segment
    while (bufferOffset < MAX_COMPONENT_LEN
           && (path[offset] != '/')
           && (path[offset] != '\0')) {
      buffer[bufferOffset++] = path[offset++];
    }

    buffer[bufferOffset] = '\0';

    // Skip trailing separator so we can determine if this
    // is the last component in the path or not.
    if (path[offset] == '/') {
      offset++;
    }

    *p_offset = offset;

    return (path[offset] != '\0');
  }



  bool walkPath(const char *filepath, SdFile& parentDir,
                bool(*callback)(SdFile& parentDir,
                                const char *filePathComponent,
                                bool isLastComponent,
                                void *object),
                void *object = NULL) {
    /*

       When given a file path (and parent directory--normally root),
       this function traverses the directories in the path and at each
       level calls the supplied callback function while also providing
       the supplied object for context if required.

         e.g. given the path '/foo/bar/baz'
              the callback would be called at the equivalent of
        '/foo', '/foo/bar' and '/foo/bar/baz'.

       The implementation swaps between two different directory/file
       handles as it traverses the directories and does not use recursion
       in an attempt to use memory efficiently.

       If a callback wishes to stop the directory traversal it should
       return false--in this case the function will stop the traversal,
       tidy up and return false.

       If a directory path doesn't exist at some point this function will
       also return false and not subsequently call the callback.

       If a directory path specified is complete, valid and the callback
       did not indicate the traversal should be interrupted then this
       function will return true.

    */


    SdFile subfile1;
    SdFile subfile2;

    char buffer[PATH_COMPONENT_BUFFER_LEN];

    unsigned int offset = 0;

    SdFile *p_parent;
    SdFile *p_child;

    SdFile *p_tmp_sdfile;

    p_child = &subfile1;

    p_parent = &parentDir;

    while (true) {

      bool moreComponents = getNextPathComponent(filepath, &offset, buffer);

      bool shouldContinue = callback((*p_parent), buffer, !moreComponents, object);

      if (!shouldContinue) {
        // TODO: Don't repeat this code?
        // If it's one we've created then we
        // don't need the parent handle anymore.
        if (p_parent != &parentDir) {
          (*p_parent).close();
        }
        return false;
      }

      if (!moreComponents) {
        break;
      }

      bool exists = (*p_child).open(*p_parent, buffer, O_RDONLY);

      // If it's one we've created then we
      // don't need the parent handle anymore.
      if (p_parent != &parentDir) {
        (*p_parent).close();
      }

      // Handle case when it doesn't exist and we can't continue...
      if (exists) {
        // We alternate between two file handles as we go down
        // the path.
        if (p_parent == &parentDir) {
          p_parent = &subfile2;
        }

        p_tmp_sdfile = p_parent;
        p_parent = p_child;
        p_child = p_tmp_sdfile;
      } else {
        return false;
      }
    }

    if (p_parent != &parentDir) {
      (*p_parent).close(); // TODO: Return/ handle different?
    }

    return true;
  }



  /*

     The callbacks used to implement various functionality follow.

     Each callback is supplied with a parent directory handle,
     character string with the name of the current file path component,
     a flag indicating if this component is the last in the path and
     a pointer to an arbitrary object used for context.

  */

  bool callback_pathExists(SdFile& parentDir, const char *filePathComponent,
                           bool /* isLastComponent */, void * /* object */) {
    /*

      Callback used to determine if a file/directory exists in parent
      directory.

      Returns true if file path exists.

    */
    SdFile child;

    bool exists = child.open(parentDir, filePathComponent, O_RDONLY);
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

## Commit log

2021-08-09 Initial upload
    First commit without schematics and board source files
2026-01-04 HW source files added
    [TVC-NanoSD-IO-2-1.brd, TVC-NanoSD-IO-2-1.sch]
